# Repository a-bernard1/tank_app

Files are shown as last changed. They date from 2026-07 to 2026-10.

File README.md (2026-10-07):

# Mini Tank — Embedded Robotic Vehicle

```
        .--._____,
     .-='=='==-, "
    (O_o_o_o_o_O)
```

A remotely controlled tracked vehicle designed and developed from scratch, combining embedded c++, robotics, 3D mechanical design and mobile software.

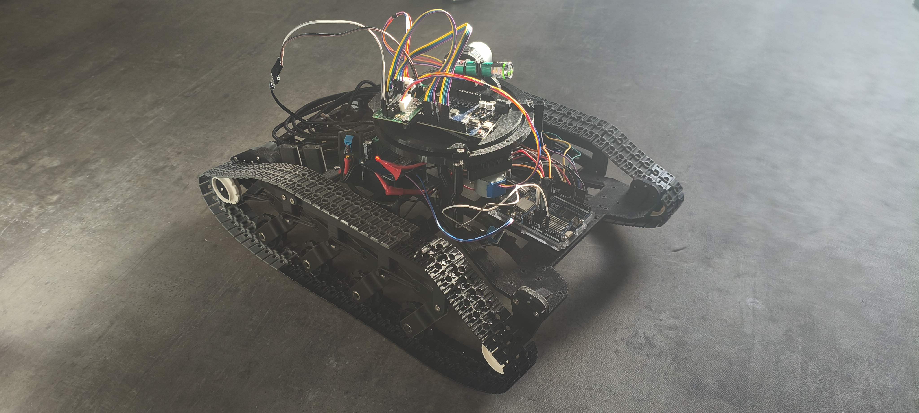
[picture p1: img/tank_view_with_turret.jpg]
Mini Tank


> *The final tank assembly with its turret* <br>

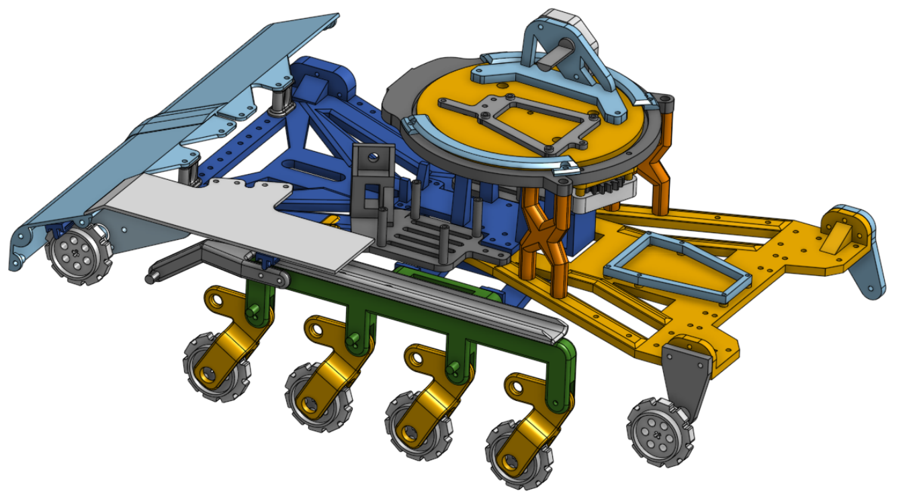
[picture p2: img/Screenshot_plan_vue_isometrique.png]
<br>

> *The tank assembly in Onshape* <br>

## System architecture and diagrams

Architecture diagram of a-bernard1/tank_app (https://gitdiagram.com/a-bernard1/tank_app?utm_source=readme&utm_medium=picture)
---

## Main Features

- Wireless tank control : Embedded C++ firmware using the Arduino framework
- Differential drive
- Turret control
- Firing mechanism control
- Bluetooth communication
- Battery voltage monitoring
- Bluetooth Low Energy communication
---

## Hardware Overview

| Component | Description |
|---|---|
| Main controller | Arduino UNO R4 WiFi |
| Turret controller | Arduino UNO R3 |
| Motor drivers | 2× BTS7960 |
| Turret controls | 2× 28BYJ-48 stepper motors |
| Power supply | Custom PCB designed in KiCad |
| Battery | 12 V LiPo |
| Chassis | Fully 3D-printed, custom-designed |
| Suspension | Pseudo-3D Christie suspension |

## Final assembly

Tank<br>
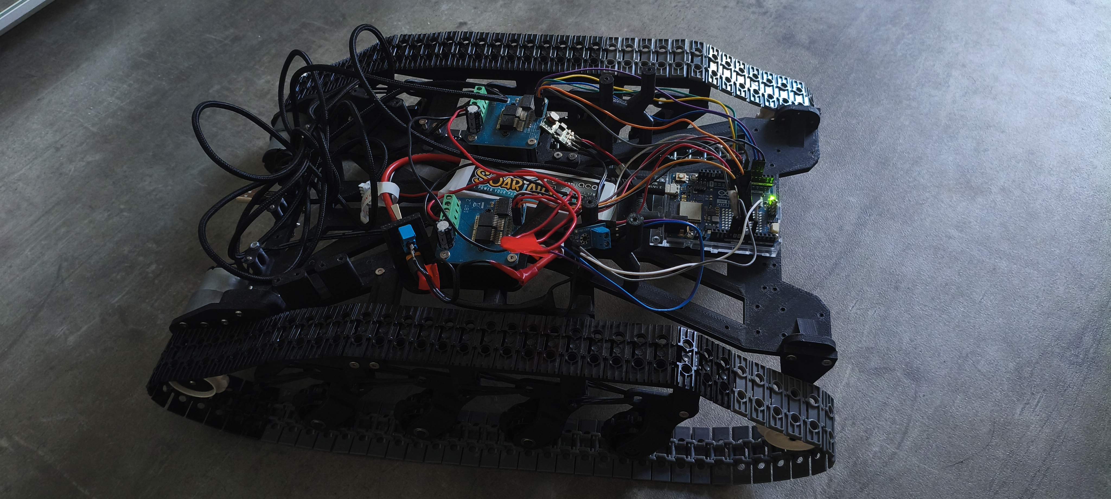
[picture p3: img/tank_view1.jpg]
Tank
<br>
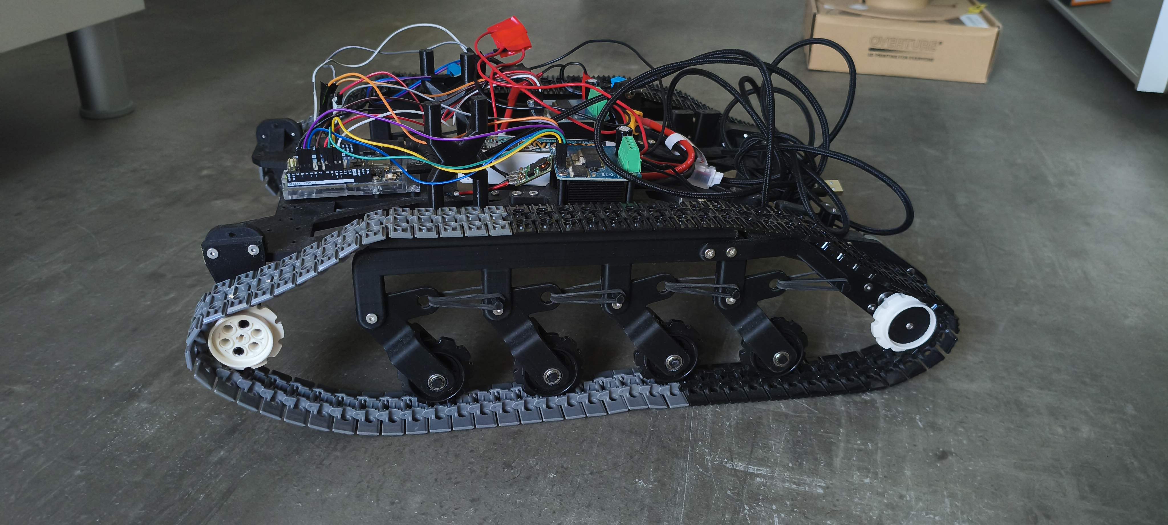
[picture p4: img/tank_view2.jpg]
Tank
<br>
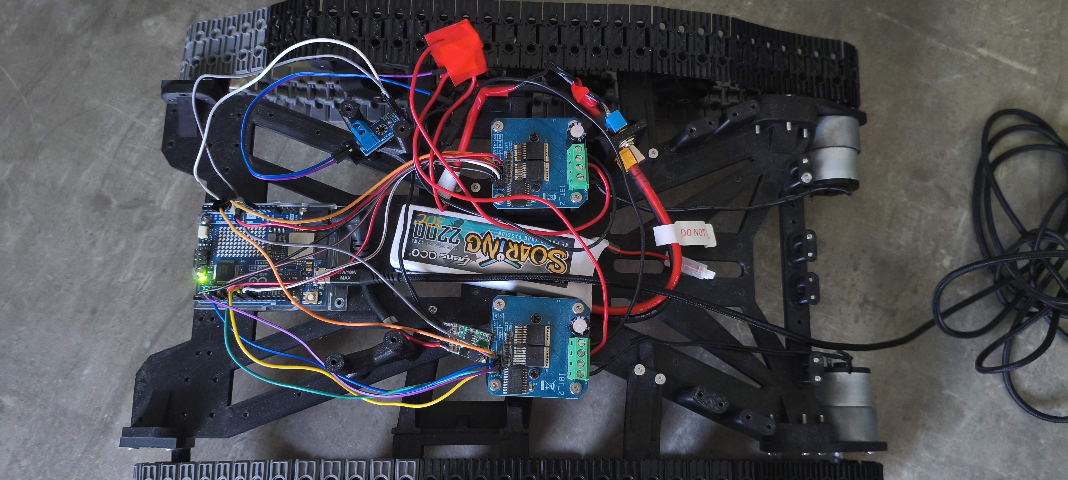
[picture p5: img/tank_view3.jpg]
Tank


## Electronics

> (mettre screenshot kicad)

## Mechanical design
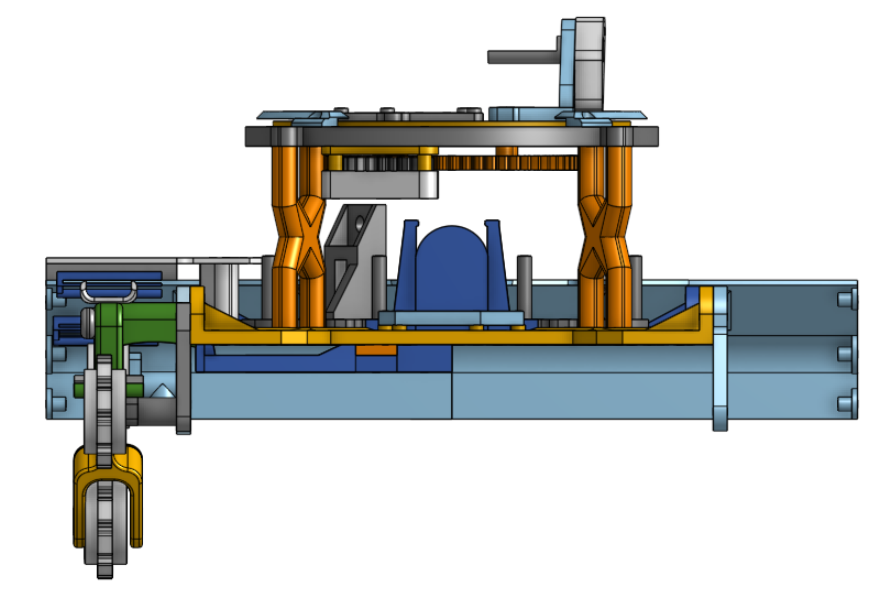
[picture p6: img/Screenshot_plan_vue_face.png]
<br>
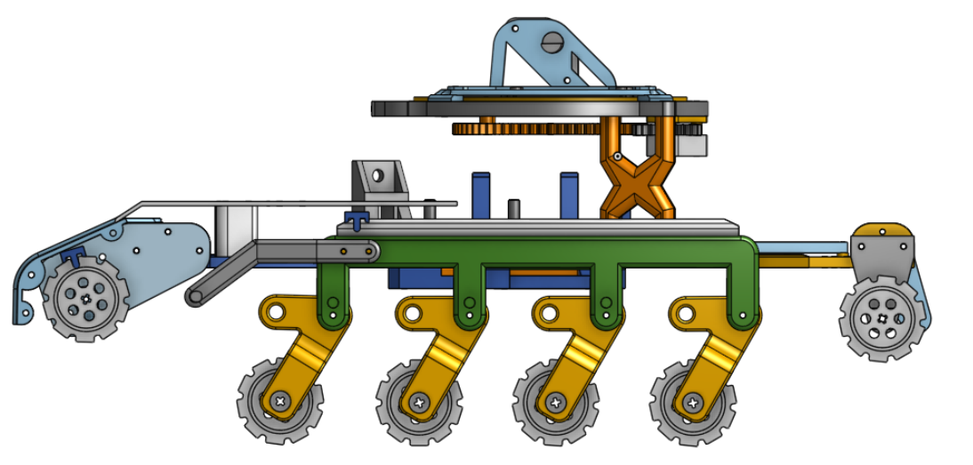
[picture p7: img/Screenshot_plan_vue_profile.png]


## Mobile app
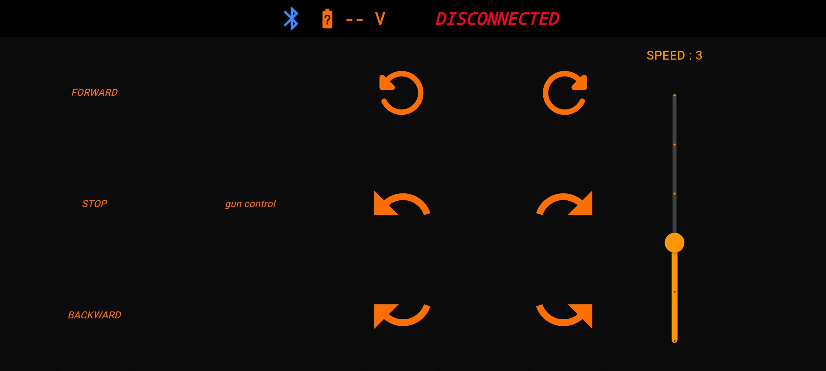
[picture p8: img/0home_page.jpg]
<br>
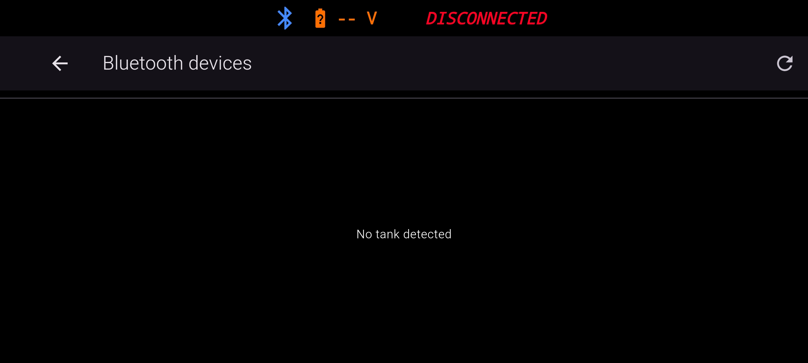
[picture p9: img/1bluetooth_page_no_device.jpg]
<br>
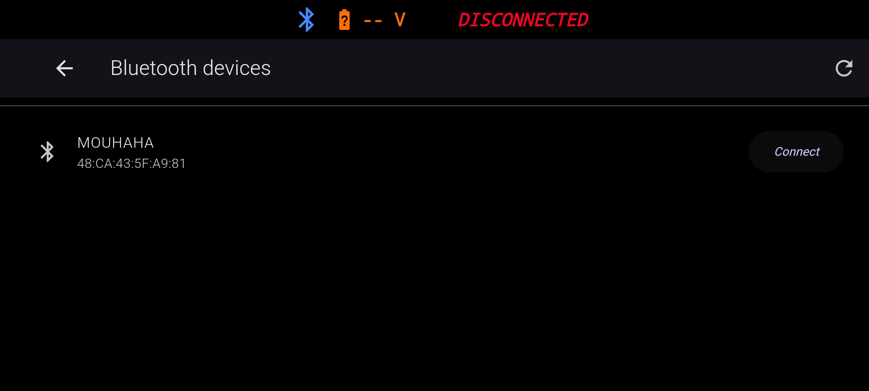
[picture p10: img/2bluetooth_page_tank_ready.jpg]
<br>
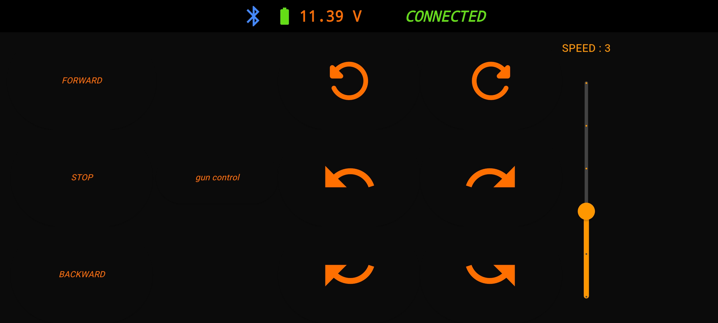
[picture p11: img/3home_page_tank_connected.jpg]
<br>
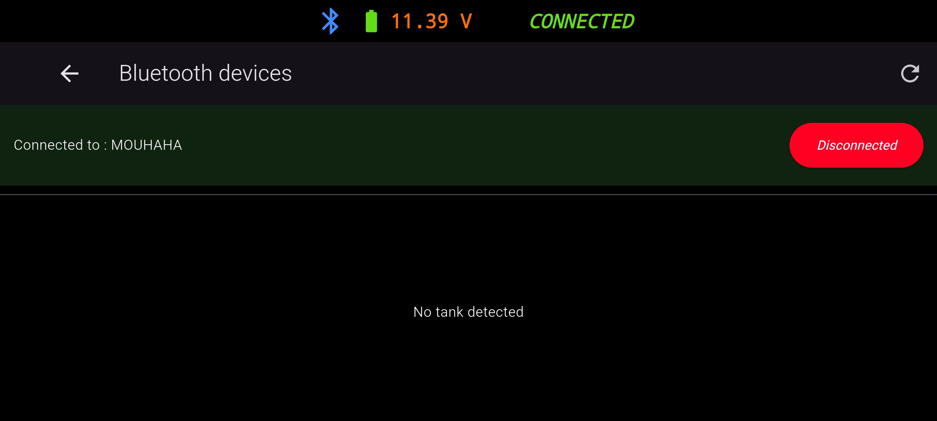
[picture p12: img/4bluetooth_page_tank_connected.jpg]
<br>

## My Contribution

I designed and developed the project from scratch, including:

- Mechanical design and 3D modeling of the chassis and turret
- Design of the custom power supply PCB using KiCad
- Embedded firmware for the tank
- Motor and turret control
- Bluetooth communication
- Android application using Flutter

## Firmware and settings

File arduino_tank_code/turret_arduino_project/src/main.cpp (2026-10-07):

#include <Arduino.h>
#include <AccelStepper.h>

AccelStepper stepper1(4,8,10,9,11);
AccelStepper stepper2(4,3,5,4,7);


void setup() {
  Serial.begin(9600);
  Serial.println("READY");

  stepper1.setMaxSpeed(500.0);
  stepper1.setAcceleration(300.0);
  stepper2.setMaxSpeed(500.0);
  stepper2.setAcceleration(300.0);
}

void loop() {

    if(Serial.available()>0){
    char c = Serial.read();

    if(c=='\r' || c=='\n')return;

    Serial.println("VALUE: ");
    Serial.println(c);

    switch (c)
    {
    case 'a':
      stepper1.move(100);
      break;
    case 'z':
      stepper1.move(-100);
      break;
    case 'q':
      stepper2.move(100);
      break;
    case 's':
      stepper2.move(-100);
      break;
    case 'm':
      stepper1.moveTo(0);
      break;
    case 'l':
      stepper2.moveTo(0);
      break;

    default:
      break;
    }
  }

  stepper1.run();
  stepper2.run();
}

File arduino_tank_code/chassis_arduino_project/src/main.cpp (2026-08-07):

#include <Arduino.h>
#include <ArduinoBLE.h>
#include "Motor.hpp"
#include "Battery.hpp"
#include "Tank.hpp"



BLEService tankService("19B10000-E8F2-537E-4F6C-D104768A1214"); // Bluetooth® Low Energy LED Service
// Bluetooth® Low Energy LED Switch Characteristic - custom 128-bit UUID, read and writable by central
BLEByteCharacteristic switchCharacteristic("19B10001-E8F2-537E-4F6C-D104768A1214", BLERead | BLEWrite);
BLEFloatCharacteristic batteryVoltageChar("19B10002-E8F2-537E-4F6C-D104768A1214", BLERead | BLENotify);
BLEByteCharacteristic speedCharacteristic("19B10003-E8F2-537E-4F6C-D104768A1214", BLERead | BLEWrite);


Motor leftMotor(10, 9, 4, 5);
Motor rightMotor(3, 11, 7, 8);
Battery battery(A0);

Tank tank = Tank(leftMotor, rightMotor, battery);

unsigned long lastBrakeTime=0;

void setup() {
	Serial.begin(9600);
	tank.begin();

    if (!BLE.begin()) {
        Serial.println("starting Bluetooth® Low Energy module failed!");
    	while (1);
  	}

	// set advertised local name and service UUID:
	BLE.setLocalName("MOUHAHA");

	BLE.setAdvertisedService(tankService);

	// add the characteristic to the service
	tankService.addCharacteristic(switchCharacteristic);
	tankService.addCharacteristic(batteryVoltageChar);
	tankService.addCharacteristic(speedCharacteristic);


	// add service
	BLE.addService(tankService);

	// set the initial value for the characteristic:
	switchCharacteristic.writeValue(0);
	batteryVoltageChar.writeValue(12.6);
	speedCharacteristic.writeValue(150);

	// start advertising
	BLE.advertise();
}

void updateBatteryBLE(){
	if(millis()-lastBrakeTime >=2000){
		lastBrakeTime = millis();
		float voltage = battery.getVoltage();

		Serial.print("TEST main::updateBatteryBLE: voltage = ");
		Serial.println(voltage);

		batteryVoltageChar.writeValue(voltage);
	}
}


void loop() {
  	BLEDevice central = BLE.central();

	if(central){
		while(central.connected()){
			tank.update();
			updateBatteryBLE();
			if(switchCharacteristic.written()){
				uint8_t cmd_received = switchCharacteristic.value();
				Direction dir = tank.command(cmd_received); 
				tank.move(dir, tank.getSpeed());
			}
			if(speedCharacteristic.written()){
				uint8_t newSpeed = speedCharacteristic.value();
				tank.setSpeed(newSpeed);
			}
		}
	}
}

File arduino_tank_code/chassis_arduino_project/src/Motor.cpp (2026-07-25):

#include "Motor.hpp"


Motor::Motor(uint8_t fwd, uint8_t back, uint8_t en1, uint8_t en2) :
    pwmForward(fwd), pwmBackward(back), enable1(en1), enable2(en2){}

void Motor::begin(){
    pinMode(pwmForward, OUTPUT);
    pinMode(pwmBackward, OUTPUT);
    pinMode(enable1, OUTPUT);
    pinMode(enable2, OUTPUT);

    digitalWrite(enable1, HIGH);
    digitalWrite(enable2, HIGH);
}

void Motor::forward(uint8_t speed){
    if(state==2 && currentSpeed>0){
        targetSpeed = speed;
        targetState = 1;
        isBraking = true;
        return;
    }

    isBraking = false;
    targetState = 1;
    targetSpeed = speed;
    state = 1;
    currentSpeed = speed;
    analogWrite(pwmForward, speed);
    analogWrite(pwmBackward, 0);
}

void Motor::backward(uint8_t speed){
    if(state==1 && currentSpeed>0){
        targetSpeed = speed;
        targetState = 2;
        isBraking = true;
        return;
    }

    isBraking = false;
    targetState = 2;
    targetSpeed = speed;
    state = 2;
    currentSpeed = speed;
    analogWrite(pwmForward, 0);
    analogWrite(pwmBackward, speed);
}

void Motor::stop(){
    if(isBraking)return;
    
    if (currentSpeed > 0) {
        isBraking = true;
        targetSpeed = 0;
        lastBrakeTime = millis();
    } else {
        analogWrite(pwmForward, 0);
        analogWrite(pwmBackward, 0);
        state = 0;
        isBraking = false;
    }
}

void Motor::updateBrake(){
    if(!isBraking) return;

    if(millis()-lastBrakeTime >=10){
        lastBrakeTime = millis();

        if(currentSpeed >=5){
            currentSpeed -= 5;
        }else{
            currentSpeed = 0;
        }
        
        if(state == 1){
            analogWrite(pwmForward, currentSpeed);
            analogWrite(pwmBackward, 0);
        }else if(state == 2){
            analogWrite(pwmForward, 0);
            analogWrite(pwmBackward, currentSpeed);
        }
        

        if(currentSpeed == 0){
            analogWrite(pwmForward, 0);
            analogWrite(pwmBackward, 0);

            if(targetState == 1){
                forward(targetSpeed);
            } else if(targetState == 2){
                backward(targetSpeed);
            }else{
                state = 0;
                isBraking = false;
            }
        }
    }
}

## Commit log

2026-07-17 feat(battery): implement voltage monitoring and averaging - create battery class to handle voltage reading and averaging - Restrict measurement to stop phases to avoid peak loads
    [Battery.cpp]
2026-07-17 feat(battery): implement the battery class to read and average voltage
2026-07-18 fix(motor): add a delay in the progressiveBrake method
    [Motor.cpp]
2026-07-18 refactor(tank): add a currentSpeed variable for the future method setSpeed
2026-07-18 refactor(main): edit the pins 6 which is 980Hz PWM instead of 490 like the others
2026-07-21 refractor(braking):replace delay with millis() for progressive brake
    [Motor.cpp]
2026-07-21 refactor(braking): use new progressive brake method from Motor class
2026-07-25 feat(motor): auto-brake before reversing track direction
    [Motor.cpp]
2026-07-28 feat(Battery): new method that checks if the battery voltage is too low for the security
    [Battery.cpp]
2026-07-28 feat(Battery): use Battery class to check battery voltage and if the it is too low, cut the transmissions to secure the tank and save battery
2026-07-30 feat(Battery): new method to measure the voltage and storing it for the other methods
2026-07-30 refactor: pass battery via constructor instead of hard-coded
2026-07-30 feat(BLE): send voltage to the bluetooth device every 2 seconds
2026-08-03 chore: remove old debug prints
2026-08-03 feat(BLE): parse and stream battery voltage from BLE notification with UUID characteristic and StreamController<double> for the UI
2026-08-07 feat: new getter getSpeed() + fix(movement): add 'break' in 2 last cases of the switch
2026-08-07 feat(speed): slider widget that allows to select a speed the finger releases the screen and use bluetooth to send the value
2026-08-09 feat(BLE): new methods to scan and select a device manually
2026-08-09 feat(BLE): add bluetooth state and button to access bluetooth menu
2026-10-07 KiCad schematic of the power supply board
    [PCB_alim_miniChar.kicad_sch]
2026-10-28 two test environments for each board
2026-10-28 feat(boards transmission): new class with sendOrder and readOrder methods
2026-10-28 test sketches to simulate the communication between the chassis board and the turret board
2026-10-28 feat: link the old keyboard Serial commands to the new transmission between two boards to drive the stepper motors
2026-10-28 update the commands to simulate the chassis baord
2026-10-29 feat(transmission): new first byte in the frame to check if an order is well formed
2026-10-29 feat(stepper motor): use disableOutput method when no movements to avoid stepper motor to heat
2026-10-29 move Transmission class to a common folder between the chassis arduino code and the turret one
